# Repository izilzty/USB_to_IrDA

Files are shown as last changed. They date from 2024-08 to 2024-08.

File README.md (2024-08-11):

# USB 转 IrDA SIR 转接板

USB转IrDA SIR转接板，支持波特率为4800~57600，可以更换晶振以支持其他波特率。

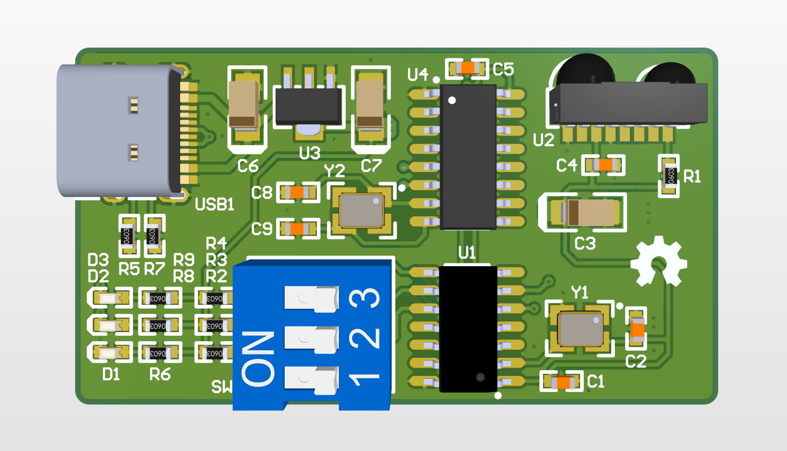
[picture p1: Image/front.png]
正面


## 硬件说明

### 1. 波特率选择

在使用3.6864MHz晶振时，支持的波特率如下表所示，通电时切换波特率后需要重新上电，串口波特率要和开关选择的波特率相同。

| 开关编号（1、2、3） | 波特率 |
| :-: | :-: |
| ON ON ON | 4800 |
| OFF ON ON | 9600 |
| ON OFF ON | 19200 |
| OFF OFF ON | 28800 |
| ON ON OFF | 57600（不稳定） |

经过测试，在57600波特率时会产生误码，这可能是由于MCP2120发送和接收送红外信号时会产生一些抖动所造成的，所以在条件允许的情况下尽量使用较低的波特率。

如果需要其他波特率，可以自行更换晶振（有源晶振），具体请参考MCP2120数据手册，开关位置为OFF时代表0。

> https://www.microchip.com/en-us/product/mcp2120

### 2. LDO滤波电容选择

因为一些LDO在使用MLCC电容时容易出现震荡，所以在选择电容时注意LDO是否支持MLCC电容，如果不支持请使用钽电容避免出现问题。

### 3. 红外收发器选择

PCB默认使用IRMS6452或IRMT6452红外收发器，选择理由主要为尺寸较大方便焊接，可以自行更改PCB使用其他类似的红外收发器。在焊接时注意去除引脚氧化层，确保连接良好。

### 4. Releases版本内的元件参数

Releases仅用于发布GERBER文件，实际元件参数后期根据情况可能会有调整，所以元件参数请以最新的Main分支为准。

### 5. 版本号说明
PCB版本号格式为：X.YZ
* Z：仅丝印有更改。
* Y：仅线路有更改，但不影响现有的功能。
* X：除丝印和线路以外的其他更改，例如PCB尺寸、通孔位置、元件位置、元件数量等等。

Y和Z相互独立，互不干扰。如果X有改变，则Y和Z全部清0。

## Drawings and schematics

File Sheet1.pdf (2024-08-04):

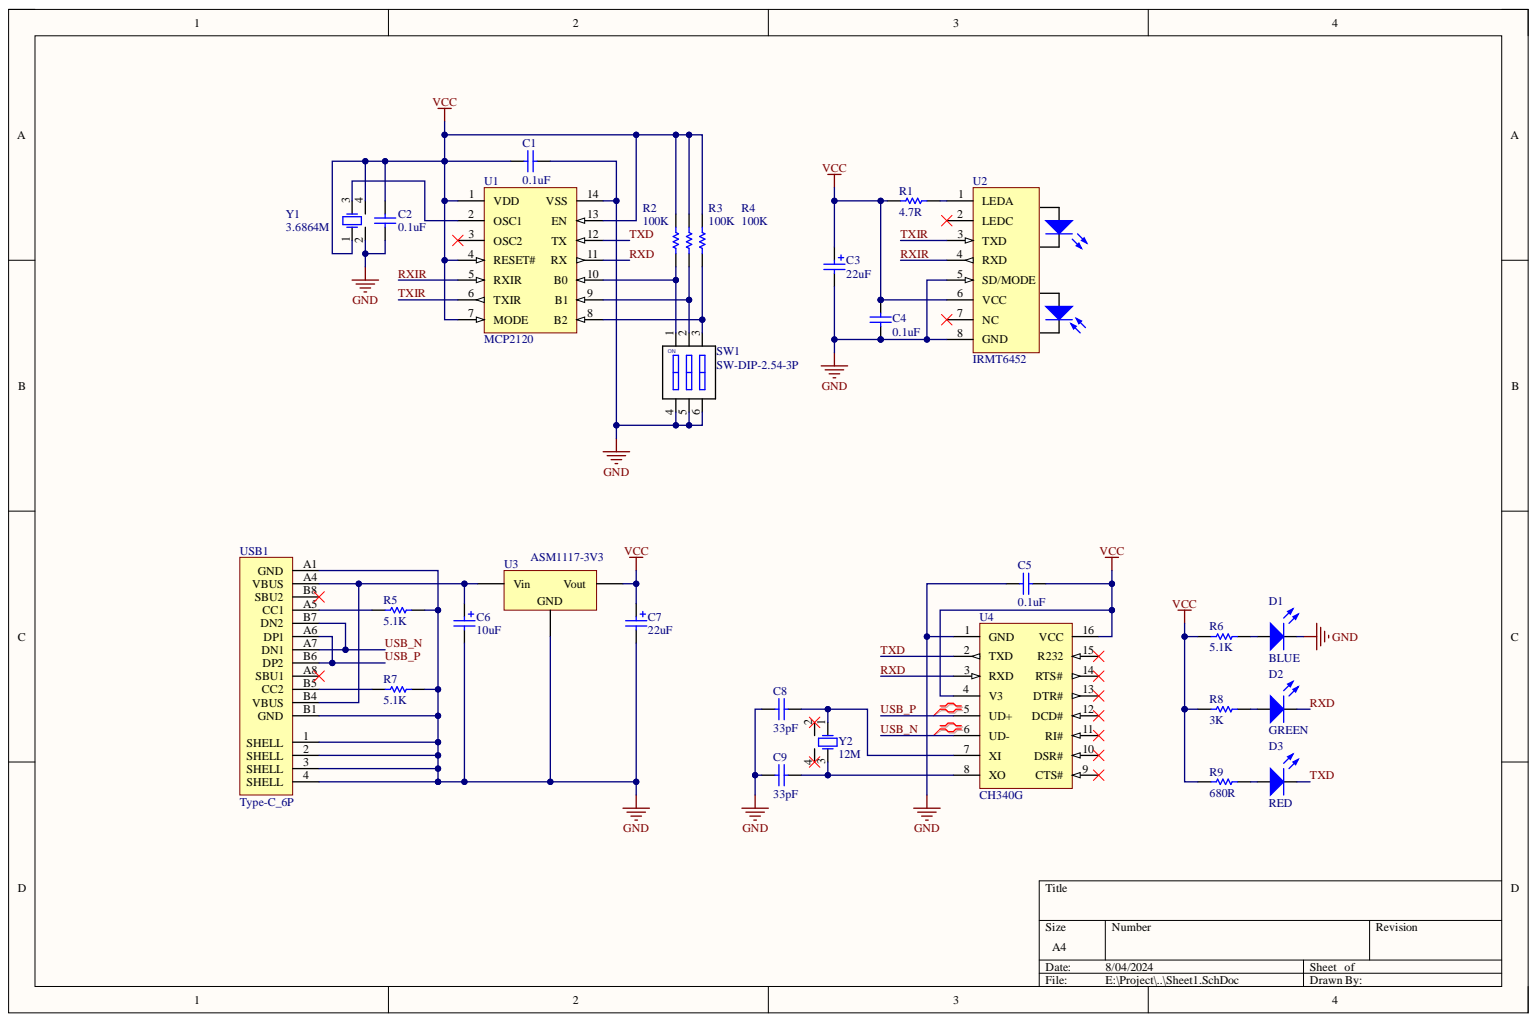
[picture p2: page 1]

Comment | Description | Designator | Footprint | LibRef | Quantity
0.1uF | | C1, C2, C4, C5 | 0603-CAP | CAP-0603 | 4
22uF | | C3, C7 | 3216-TCAP_M | CAP-T-3216 | 2
10uF | | C6 | 3216-TCAP_M | CAP-T-3216 | 1
33pF | | C8, C9 | 0603-CAP | CAP-0603 | 2
BLUE | | D1 | 0603-LED | LED-0603 | 1
GREEN | | D2 | 0603-LED | LED-0603 | 1
RED | | D3 | 0603-LED | LED-0603 | 1
4.7R | | R1 | 0603-RES | RES-0603 | 1
100K | | R2, R3, R4 | 0603-RES | RES-0603 | 3
5.1K | | R5, R6, R7 | 0603-RES | RES-0603 | 3
3K | | R8 | 0603-RES | RES-0603 | 1
680R | | R9 | 0603-RES | RES-0603 | 1
SW-DIP-2.54-3P | | SW1 | SWITCH-DIP-2.54-3P | SW-DIP-2.54-3P | 1
MCP2120 | Infrared Encoder/Decoder | U1 | SOP-14_M | MCP2120 | 1
IRMT6452 | 4 Mb/s Infrared Data Transceiver | U2 | IRMT6452_M | IRMT6452 | 1
ASM1117-3V3 | Voltage Regular (SOT-89) | U3 | SOT-89-3_M | VREG-SOT-89 | 1
CH340G | USB转串口芯片 | U4 | SOP-16_M | CH340G | 1
Type-C_6P | | USB1 | TYPE-C_16P | Type-C_6P | 1
3.6864M | oscillator | Y1 | CRYSTAL_3225SMD_ M | XTAL-3225SMD | 1
12M | crystal | Y2 | CRYSTAL_3225SMD_ M | XTAL-3225SMD | 1

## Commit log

2024-08-04 首次提交
    [PCB1.GBL, PCB1.GBO, PCB1.GBS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]
2024-08-04 更新说明文档
2024-08-11 更新波特率说明
